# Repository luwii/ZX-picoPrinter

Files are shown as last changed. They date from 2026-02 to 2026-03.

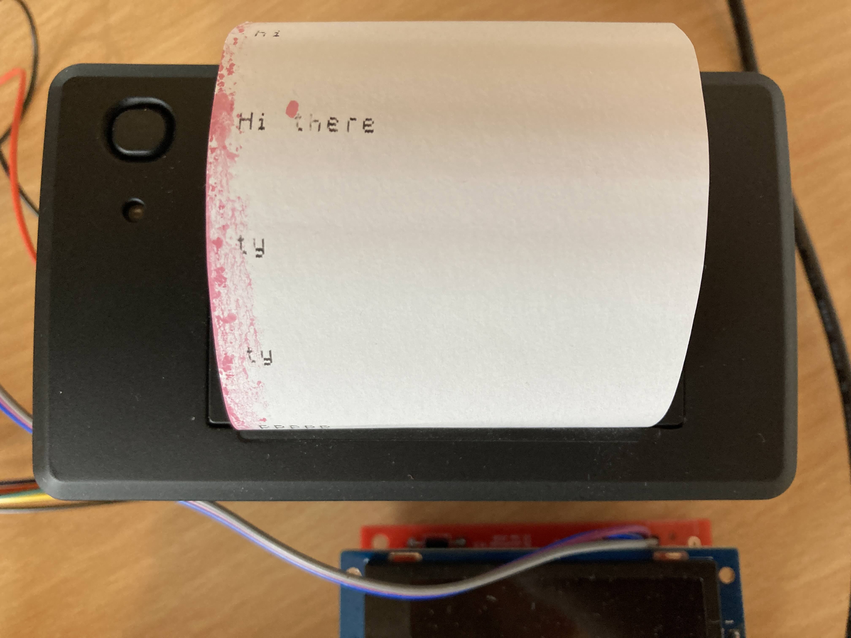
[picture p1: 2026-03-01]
Documentation/zx_printout.jpeg

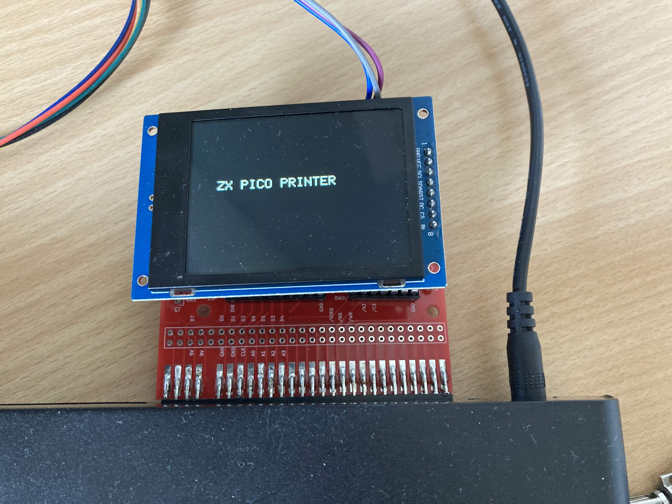
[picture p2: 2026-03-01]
Documentation/zx_screen.jpeg

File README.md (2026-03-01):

# ZX-picoPrinter

## Project Description
ZX-picoPrinter is a compact and efficient printer solution designed for use with the Raspberry Pi Pico. This project aims to provide an easy-to-use interface that is simple to construct.

## Features
- Compact design suitable for various projects
- Easy setup and integration with Raspberry Pi Pico
- Optional screen to preview the print

## Hardware Requirements
- Raspberry Pi Pico
- Compatible thermal printer
- Power supply for the printer
- Connecting cables (USB or serial)
- Custom circuit board 
- Logic chips

## Getting Started Guide
1. **Prerequisites**: Make sure you have installed the necessary software tools for Raspberry Pi Pico development. (VSC with official PI plugin was used)
2. **Clone the Repository**: ```git clone https://github.com/luwii/ZX-picoPrinter.git``` 
3. **Connect the Hardware**: Follow the wiring instructions provided in the documentation. The screen and printer work indepently, you only need one of them
4. **Upload the Code**: Use your preferred development environment to upload the provided codes to the Raspberry Pi Pico.
5. **Run the Application**: Start the application and test with LPRINT

## Documentation References
- [Printer Manual](https://github.com/luwii/ZX-picoPrinter/blob/main/Documentation/zxpicoprinter.pdf)
- [Raspberry Pi Pico Documentation](https://www.raspberrypi.com/documentation/microcontrollers/pico-series.html)

## License
This project is licensed under the MIT License. See the LICENSE file for more details.

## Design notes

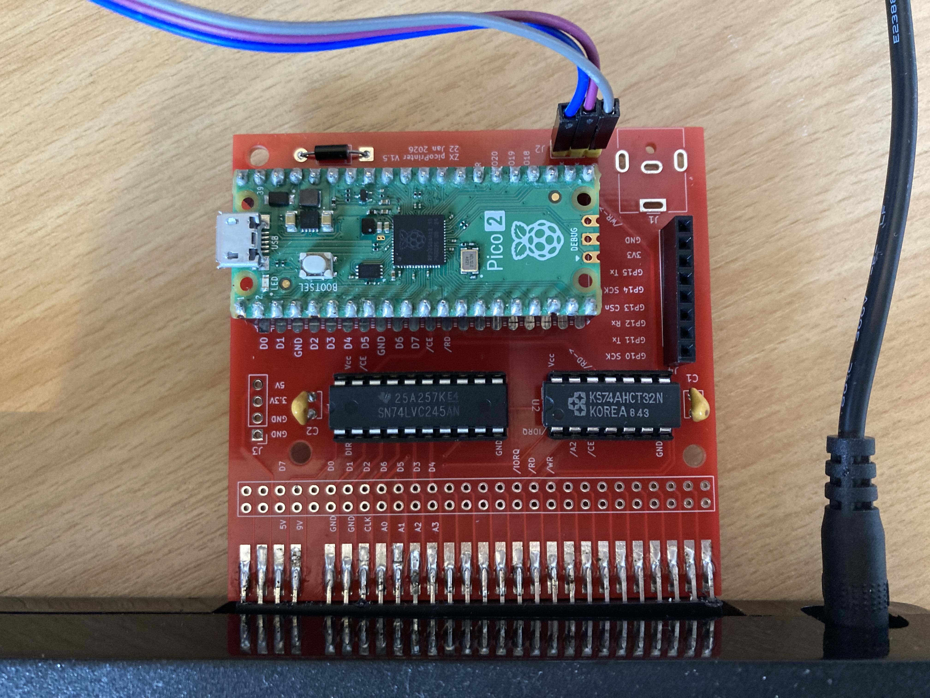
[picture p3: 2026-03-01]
Documentation/zx_board.jpeg

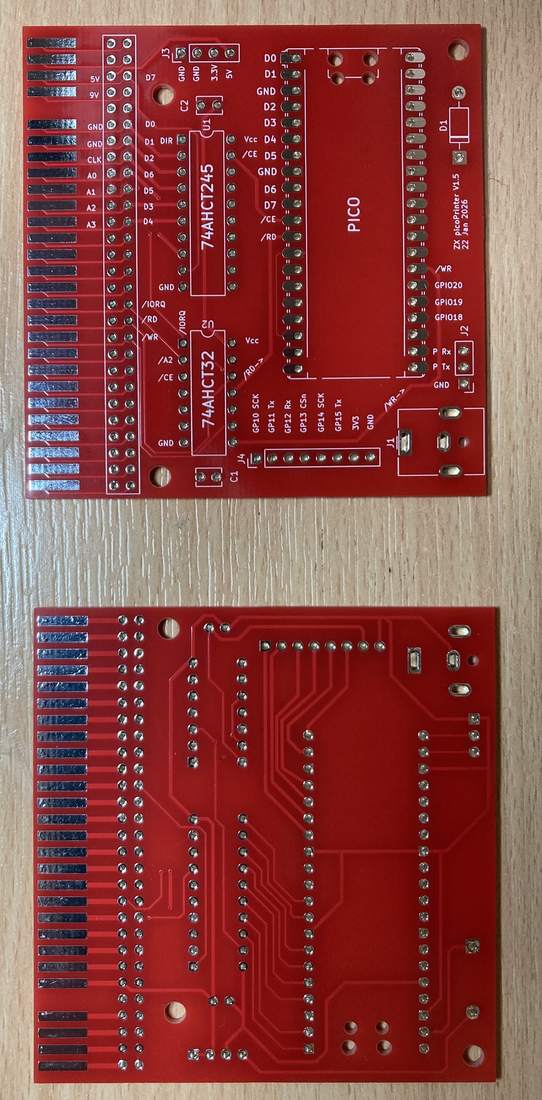
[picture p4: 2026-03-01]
Documentation/zx_pcb.jpeg

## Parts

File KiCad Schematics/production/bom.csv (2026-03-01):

Designator | Footprint | Quantity | Value | LCSC Part #
A1 | RaspberryPi_Pico_Common_Unspecified | 1 | RaspberryPi_Pico
C1, C2 | C_Disc_D3.8mm_W2.6mm_P2.50mm | 2 | C_Small
D1 | D_DO-41_SOD81_P10.16mm_Horizontal | 1 | 1N4004
J2 | PinHeader_1x03_P2.54mm_Vertical | 1 | Serial
J3 | PinHeader_1x04_P2.54mm_Vertical | 1 | Power
J4 | PinHeader_1x08_P2.54mm_Vertical | 1 | Conn_01x08_Pin
U1 | DIP-20_W7.62mm | 1 | 74AHCT245
U2 | CERDIP-14_W7.62mm_SideBrazed | 1 | 74AHCT32
Z1 | ZX_Bus_Edge_Connector | 1 | ZX48Bus
Z2 | ZX_Bus_Pin_Header | 1 | ZX48Bus

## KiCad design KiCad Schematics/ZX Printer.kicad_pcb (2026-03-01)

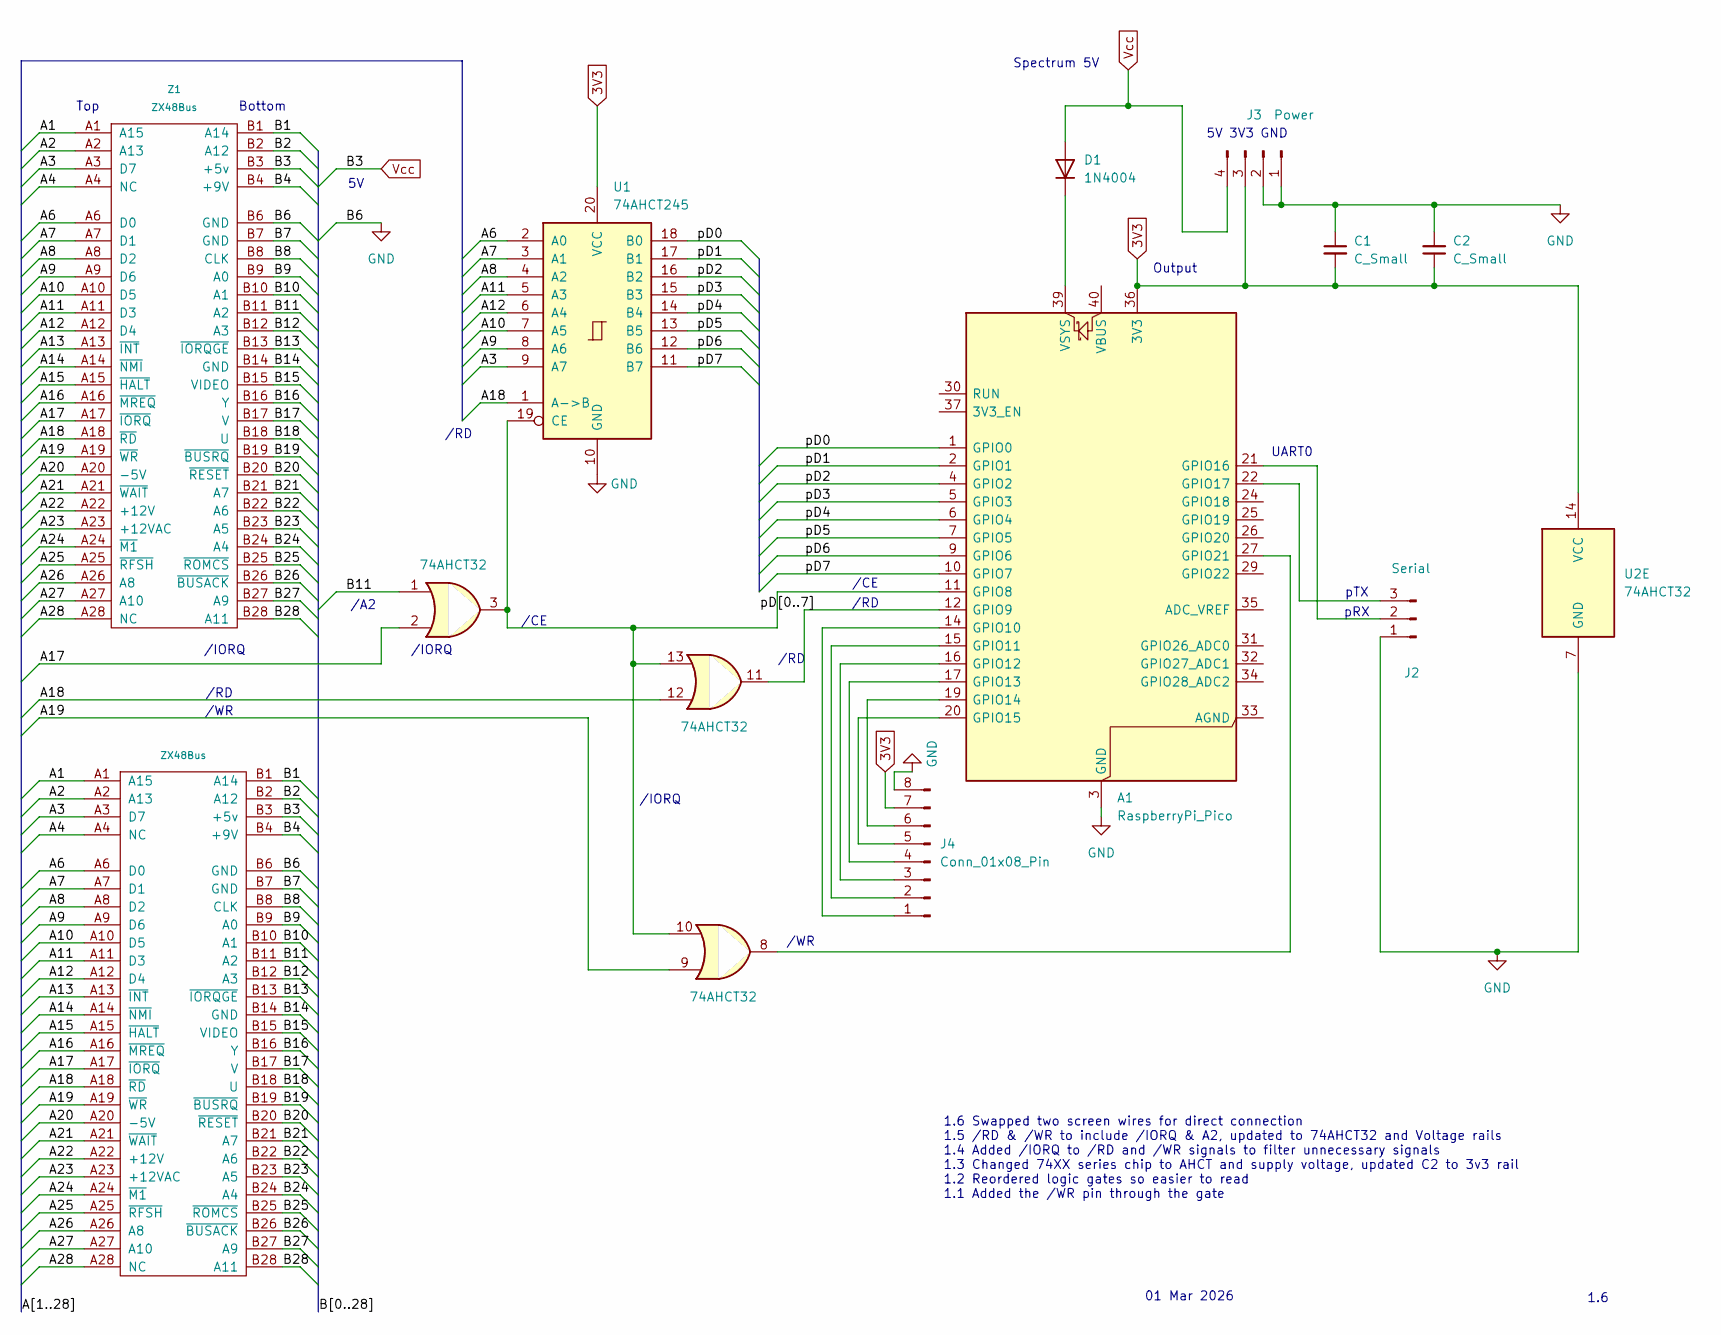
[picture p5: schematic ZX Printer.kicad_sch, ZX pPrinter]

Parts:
A1: RaspberryPi_Pico; RaspberryPi_Pico_Common_Unspecified
C1, C2: C_Small; C_Disc_D3.8mm_W2.6mm_P2.50mm
D1: 1N4004; D_DO-41_SOD81_P10.16mm_Horizontal
J2: Serial; PinHeader_1x03_P2.54mm_Vertical
J3: Power; PinHeader_1x04_P2.54mm_Vertical
J4: Conn_01x08_Pin; PinHeader_1x08_P2.54mm_Vertical
U1: 74AHCT245; DIP-20_W7.62mm
U2: 74AHCT32; CERDIP-14_W7.62mm_SideBrazed
Z1: ZX48Bus; ZX_Bus_Edge_Connector
Z2: ZX48Bus; ZX_Bus_Pin_Header

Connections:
3V3: A1.36 (3V3), C1.2, C2.1, J3.3, J4.7, U1.20 (VCC), U2.14 (VCC)
/A1: Z1.A1 (A15), Z2.A1 (A15)
/A2: Z1.A2 (A13), Z2.A2 (A13)
/A3: U1.9 (A7), Z1.A3 (D7), Z2.A3 (D7)
/A4: Z1.A4 (NC), Z2.A4 (NC)
/A6: U1.2 (A0), Z1.A6 (D0), Z2.A6 (D0)
/A7: U1.3 (A1), Z1.A7 (D1), Z2.A7 (D1)
/A8: U1.4 (A2), Z1.A8 (D2), Z2.A8 (D2)
/A9: U1.8 (A6), Z1.A9 (D6), Z2.A9 (D6)
/A10: U1.7 (A5), Z1.A10 (D5), Z2.A10 (D5)
/A11: U1.5 (A3), Z1.A11 (D3), Z2.A11 (D3)
/A12: U1.6 (A4), Z1.A12 (D4), Z2.A12 (D4)
/A13: Z1.A13 (~INT), Z2.A13 (~INT)
/A14: Z1.A14 (~NMI), Z2.A14 (~NMI)
/A15: Z1.A15 (~HALT), Z2.A15 (~HALT)
/A16: Z1.A16 (~MREQ), Z2.A16 (~MREQ)
/A17: U2.2, Z1.A17 (~IORQ), Z2.A17 (~IORQ)
/A18: U1.1 (A->B), U2.12, Z1.A18 (~RD), Z2.A18 (~RD)
/A19: U2.9, Z1.A19 (~WR), Z2.A19 (~WR)
/A20: Z1.A20 (-5V), Z2.A20 (-5V)
/A21: Z1.A21 (~WAIT), Z2.A21 (~WAIT)
/A22: Z1.A22 (+12V), Z2.A22 (+12V)
/A23: Z1.A23 (+12VAC), Z2.A23 (+12VAC)
/A24: Z1.A24 (~M1), Z2.A24 (~M1)
/A25: Z1.A25 (~RFSH), Z2.A25 (~RFSH)
/A26: Z1.A26 (A8), Z2.A26 (A8)
/A27: Z1.A27 (A10), Z2.A27 (A10)
/A28: Z1.A28 (NC), Z2.A28 (NC)
/B1: Z1.B1 (A14), Z2.B1 (A14)
/B2: Z1.B2 (A12), Z2.B2 (A12)
/B4: Z1.B4 (+9V), Z2.B4 (+9V)
/B7: Z1.B7 (GND), Z2.B7 (GND)
/B8: Z1.B8 (CLK), Z2.B8 (CLK)
/B9: Z1.B9 (A0), Z2.B9 (A0)
/B10: Z1.B10 (A1), Z2.B10 (A1)
/B11: U2.1, Z1.B11 (A2), Z2.B11 (A2)
/B12: Z1.B12 (A3), Z2.B12 (A3)
/B13: Z1.B13 (~IORQGE), Z2.B13 (~IORQGE)
/B14: Z1.B14 (GND), Z2.B14 (GND)
/B15: Z1.B15 (VIDEO), Z2.B15 (VIDEO)
/B16: Z1.B16 (Y), Z2.B16 (Y)
/B17: Z1.B17 (V), Z2.B17 (V)
/B18: Z1.B18 (U), Z2.B18 (U)
/B19: Z1.B19 (~BUSRQ), Z2.B19 (~BUSRQ)
/B20: Z1.B20 (~RESET), Z2.B20 (~RESET)
/B21: Z1.B21 (A7), Z2.B21 (A7)
/B22: Z1.B22 (A6), Z2.B22 (A6)
/B23: Z1.B23 (A5), Z2.B23 (A5)
/B24: Z1.B24 (A4), Z2.B24 (A4)
/B25: Z1.B25 (~ROMCS), Z2.B25 (~ROMCS)
/B26: Z1.B26 (~BUSACK), Z2.B26 (~BUSACK)
/B27: Z1.B27 (A9), Z2.B27 (A9)
/B28: Z1.B28 (A11), Z2.B28 (A11)
/pD0: A1.1 (GPIO0), U1.18 (B0)
/pD1: A1.2 (GPIO1), U1.17 (B1)
/pD2: A1.4 (GPIO2), U1.16 (B2)
/pD3: A1.5 (GPIO3), U1.15 (B3)
/pD4: A1.6 (GPIO4), U1.14 (B4)
/pD5: A1.7 (GPIO5), U1.13 (B5)
/pD6: A1.9 (GPIO6), U1.12 (B6)
/pD7: A1.10 (GPIO7), U1.11 (B7)
GND: A1.3 (GND), A1.8 (GND), A1.13 (GND), A1.18 (GND), A1.23 (GND), A1.28 (GND), A1.38 (GND), C1.1, C2.2, J2.1, J3.1, J3.2, J4.8, U1.10 (GND), U2.7 (GND), Z1.B6 (GND), Z2.B6 (GND)
unnamed: A1.11 (GPIO8), U1.19 (CE), U2.3, U2.10, U2.13
unnamed: A1.12 (GPIO9), U2.11
unnamed: A1.14 (GPIO10), J4.1
unnamed: A1.15 (GPIO11), J4.2
unnamed: A1.16 (GPIO12), J4.3
unnamed: A1.17 (GPIO13), J4.4
unnamed: A1.19 (GPIO14), J4.6
unnamed: A1.20 (GPIO15), J4.5
unnamed: A1.21 (GPIO16), J2.2
unnamed: A1.22 (GPIO17), J2.3
unnamed: A1.27 (GPIO21), U2.8
unnamed: A1.39 (VSYS), D1.1 (K)
Vcc: D1.2 (A), J3.4, Z1.B3 (+5v), Z2.B3 (+5v)

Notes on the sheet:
3V3
/IORQ
UART0
Bottom
/WR
/RD
1.6
/CE
Top
Spectrum 5V
GND
Output
/A2
pTX
01 Mar 2026
1.6 Swapped two screen wires for direct connection 1.5 /RD & /WR to include /IORQ & A2, updated to 74AHCT32 and Voltage rails 1.4 Added /IORQ to /RD and /WR signals to filter unnecessary signals 1.3 Changed 74XX series chip to AHCT and supply voltage, updated C2 to 3v3 rail 1.2 Reordered logic gate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
pRX

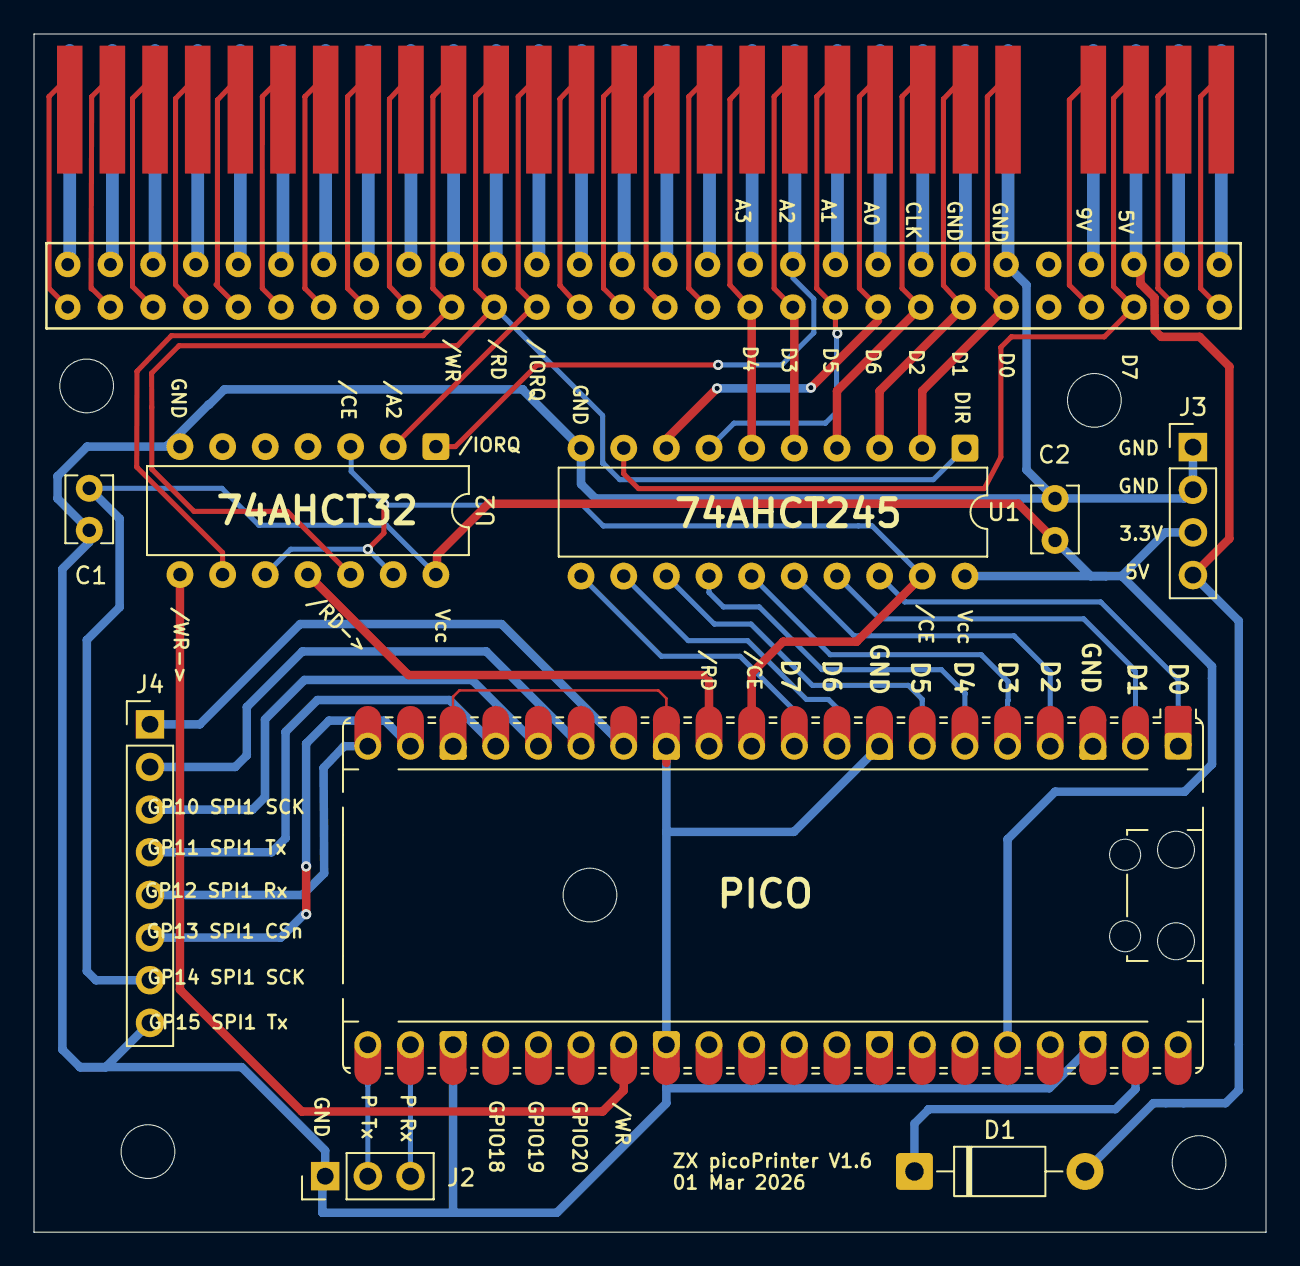
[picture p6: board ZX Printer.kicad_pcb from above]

Board: 2 copper layers, 73.4 x 71.4 mm, 11 parts (0 on the bottom side), 75 nets.

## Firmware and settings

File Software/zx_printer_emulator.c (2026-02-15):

#include <stdio.h>
#include <string.h>
#include <stdlib.h>
#include "pico/stdlib.h"
#include "hardware/pio.h"
#include "hardware/dma.h"
#include "hardware/spi.h"
#include "hardware/uart.h"
#include "zx_printer_emulator.pio.h"
#include "st7789.h"

// --- EM5820 Printer Definitions ---
#define PRINTER_UART uart0
#define PRINTER_BAUD 9600
#define PRINTER_TX_PIN 16
#define PRINTER_RX_PIN 17

// --- ZX Printer Emulator Definitions ---
#define DEBUG_VERBOSE 1
#define DISPLAY_MODE 0  // 0 = first 80 pixels, 1 = last 80 pixels for debug dump
#define ZX_DATA_BASE 0
#define ZX_CS_PIN 8
#define ZX_PRD_PIN 9
#define DEBUG_PIN 18
#define ZX_PWR_PIN 21

static int PRINTER_SCALE_H_PERCENT = 100;
static int PRINTER_SCALE_V_PERCENT = 100;

// --- ST7789 Display Pins ---
#define DISP_SCK 10
#define DISP_MOSI 11
#define DISP_RST 13
#define DISP_DC 12
#define DISP_CS 14
#define DISP_BL 15

// ESC/POS Constants
const uint8_t CMD_INIT[] = {0x1B, 0x40};

// Buffer size
#define BUFFER_SIZE 65536
static uint8_t buffer[BUFFER_SIZE];
static uint8_t cleaned[BUFFER_SIZE];  // Cleaned pixel-only buffer

// --- Clean buffer: parse and extract only pixel bytes, skipping controls ---
uint32_t clean_pixel_buffer(uint8_t* raw, uint32_t raw_size) {
    uint32_t cleaned_idx = 0;
    uint32_t skipped = 0;
    uint32_t i = 0;

    while (i < raw_size) {
        uint8_t b = raw[i];
        if (b == 0x04) {  // Skip stop (motor off)
            skipped++;
            i++;
            continue;
        }
        if (b == 0x00 || b == 0x02) {  // Speed byte: skip it, then copy next 256 pixels
            skipped++;
            i++;
            for (uint32_t p = 0; p < 256 && i < raw_size; p++) {
                // Copy pixel byte (may be 0x00/0x02/0x80/0x82)
                cleaned[cleaned_idx++] = raw[i];
                i++;
            }
            continue;
        }
        // Unexpected byte: skip (e.g., BREAK or error cases)
        skipped++;
        i++;
    }

    // Warn if incomplete last line
    if (cleaned_idx % 256 != 0 && DEBUG_VERBOSE && stdio_usb_connected()) {
        printf("Warning: Incomplete last line (%lu extra bytes)\n", (unsigned long)(cleaned_idx % 256));
    }

    if (DEBUG_VERBOSE && stdio_usb_connected()) {
        printf("Cleaned buffer: %lu bytes (skipped %lu control/unexpected bytes)\n", 
               (unsigned long)cleaned_idx, (unsigned long)skipped);
    }

    return cleaned_idx;
}

// --- Thermal print function (updated to use clean pixel stream) ---
void print_buffer_to_thermal(uint8_t *buf, uint32_t num_lines, bool unused_is_copy) {
    (void)unused_is_copy;  // No longer needed

    // Set line spacing to 0 for continuous image
    const uint8_t cmd_no_spacing[] = {0x1B, 0x33, 0x00};
    uart_write_blocking(PRINTER_UART, cmd_no_spacing, 3);

    const int src_w = 256;
    const int src_h = (int)num_lines;

    int dst_w = (src_w * PRINTER_SCALE_H_PERCENT + 50) / 100; if (dst_w < 1) dst_w = 1;
    int dst_h = (src_h * PRINTER_SCALE_V_PERCENT + 50) / 100; if (dst_h < 1) dst_h = 1;

    uint8_t *dst = calloc(dst_w * dst_h, 1);
    if (!dst) {
        dst_w = src_w; dst_h = src_h;
    }

    // Area-averaging downscale
    for (int dy = 0; dy < dst_h; dy++) {
        int sy0 = (dy * src_h) / dst_h;
        int sy1 = ((dy + 1) * src_h) / dst_h - 1;
        if (sy1 < sy0) sy1 = sy0;
        for (int dx = 0; dx < dst_w; dx++) {
            int sx0 = (dx * src_w) / dst_w;
            int sx1 = ((dx + 1) * src_w) / dst_w - 1;
            if (sx1 < sx0) sx1 = sx0;
            int total = (sx1 - sx0 + 1) * (sy1 - sy0 + 1);
            int ones = 0;
            for (int sy = sy0; sy <= sy1; sy++) {
                uint32_t pixel_start = sy * 256;  // Now always 256-byte lines
                for (int sx = sx0; sx <= sx1; sx++) {
                    uint32_t idx = pixel_start + sx;
                    if (idx < BUFFER_SIZE && (buf[idx] & 0x80)) ones++;
                }
            }
            if (dst) dst[dy * dst_w + dx] = (ones * 2 >= total) ? 1 : 0;
        }
    }

    // Send as ESC/POS graphics (8-dot mode)
    for (int row_base = 0; row_base < dst_h; row_base += 8) {
        int n = dst_w;
        uint8_t header[5] = {0x1B, 0x2A, 0x00, (uint8_t)(n & 0xFF), (uint8_t)((n >> 8) & 0xFF)};
        uart_write_blocking(PRINTER_UART, header, sizeof(header));

        for (int col = 0; col < dst_w; col++) {
            uint8_t out = 0;
            for (int bit = 0; bit < 8; bit++) {
                int dy = row_base + bit;
                if (dy >= dst_h) break;
                uint8_t pix = dst ? dst[dy * dst_w + col] : 0;
                if (pix) out |= (1u << (7 - bit));
            }
            uart_write_blocking(PRINTER_UART, &out, 1);
        }
        uint8_t lf = 0x0A;
        uart_write_blocking(PRINTER_UART, &lf, 1);
        sleep_ms(2);
    }

    if (dst) free(dst);
    const uint8_t cmd_reset_spacing[] = {0x1B, 0x32};
    uart_write_blocking(PRINTER_UART, cmd_reset_spacing, 2);
}

// Debug helper: print cleaned captured pixel data to USB stdio as ASCII art.
// Runs only when `DEBUG_VERBOSE` is enabled; respects `DISPLAY_MODE` and
// a configurable pixel count for the dump.
static void debug_print_cleaned_dump(uint8_t *cleaned_buf, uint32_t cleaned_size, uint32_t num_lines) {
#if DEBUG_VERBOSE
    const uint32_t DEBUG_DISPLAY_PIXELS = 80; // change this to show different widths
    uint32_t display_pixels = DEBUG_DISPLAY_PIXELS;
    uint32_t pixel_offset = (DISPLAY_MODE == 0) ? 0 : (256 - display_pixels);

    printf("\n=== DEBUG: Cleaned data dump ===\n");
    printf("Lines: %lu, Display pixels: %lu, Offset: %lu\n",
           (unsigned long)num_lines, (unsigned long)display_pixels, (unsigned long)pixel_offset);

    for (uint32_t line = 0; line < num_lines; line++) {
        printf("Line %3lu: ", (unsigned long)line);
        uint32_t pixel_start = line * 256;
        for (uint32_t pixel = 0; pixel < display_pixels; pixel++) {
            uint32_t idx = pixel_start + pixel_offset + pixel;
            if (idx < cleaned_size) {
                uint8_t data = cleaned_buf[idx];
                printf("%c", (data & 0x80) ? '#' : ' ');
            } else {
                printf(" ");
            }
        }
        printf("\n");
    }
    printf("=== End DEBUG dump ===\n\n");
#endif
}

int main() {
    stdio_init_all();

    // 1. Init thermal printer UART
    uart_init(PRINTER_UART, PRINTER_BAUD);
    uart_set_format(PRINTER_UART, 8, 1, UART_PARITY_NONE);
    gpio_set_function(PRINTER_TX_PIN, GPIO_FUNC_UART);
    gpio_set_function(PRINTER_RX_PIN, GPIO_FUNC_UART);
    sleep_ms(1000);
    uart_write_blocking(PRINTER_UART, CMD_INIT, sizeof(CMD_INIT));

    // Debug blinker if verbose
#if DEBUG_VERBOSE
    gpio_init(DEBUG_PIN);
    gpio_set_dir(DEBUG_PIN, GPIO_OUT);
    for (int i = 0; i < 5; i++) {
        gpio_put(DEBUG_PIN, 1);
        uart_puts(PRINTER_UART, "DEBUG_VERBOSE is on\n");
        sleep_ms(100);
        gpio_put(DEBUG_PIN, 0);
        sleep_ms(100);
    }
#endif

    // 2. Init ST7789 display
    st7789_config_t display_cfg = {
        .spi = spi1, .pin_sck = DISP_SCK, .pin_mosi = DISP_MOSI,
        .pin_rst = DISP_RST, .pin_dc = DISP_DC, .pin_cs = DISP_CS, .pin_bl = DISP_BL
    };
    st7789_init(&display_cfg);
    st7789_fill_screen(ST7789_BLACK);
    st7789_draw_string(40, 100, "ZX PICO PRINTER", ST7789_WHITE, ST7789_BLACK, 2);
    st7789_fill_rect(220, 0, 100, 240, ST7789_BLACK);

    if (stdio_usb_connected()) {
        printf("\n====================================\n");
        printf("ZX Printer Emulator & EM5820\n");
        printf("====================================\n");
    }

    // 3. ZX bus GPIO setup
    gpio_init(ZX_CS_PIN); gpio_init(ZX_PRD_PIN); gpio_init(ZX_PWR_PIN);
    gpio_set_dir(ZX_CS_PIN, GPIO_IN);
    gpio_set_dir(ZX_PRD_PIN, GPIO_IN);
    gpio_set_dir(ZX_PWR_PIN, GPIO_IN);
    gpio_pull_up(ZX_CS_PIN);
    gpio_pull_up(ZX_PRD_PIN);
    gpio_pull_up(ZX_PWR_PIN);

    // 4. PIO setup
    PIO pio = pio0;
    uint offset = pio_add_program(pio, &zx_printer_emulator_program);
    uint sm = pio_claim_unused_sm(pio, true);
    pio_sm_config c = zx_printer_emulator_program_get_default_config(offset);
    sm_config_set_in_pins(&c, ZX_DATA_BASE);
    sm_config_set_out_pins(&c, ZX_DATA_BASE, 8);
    sm_config_set_set_pins(&c, ZX_DATA_BASE, 8);
    sm_config_set_sideset_pins(&c, DEBUG_PIN);
    sm_config_set_in_shift(&c, false, true, 8);
    sm_config_set_jmp_pin(&c, ZX_PRD_PIN);
    pio_sm_init(pio, sm, offset, &c);
    for (int i = 0; i < 8; i++) pio_gpio_init(pio, ZX_DATA_BASE + i);
    pio_gpio_init(pio, DEBUG_PIN);
    pio_sm_set_consecutive_pindirs(pio, sm, DEBUG_PIN, 1, true);
    pio_sm_set_pins_with_mask(pio, sm, 0, (1u << DEBUG_PIN));
    pio_sm_put_blocking(pio, sm, 0x81);

    // 5. DMA setup
    int dma_chan = dma_claim_unused_channel(true);
    dma_channel_config dma_config = dma_channel_get_default_config(dma_chan);
    channel_config_set_transfer_data_size(&dma_config, DMA_SIZE_8);
    channel_config_set_read_increment(&dma_config, false);
    channel_config_set_write_increment(&dma_config, true);
    channel_config_set_dreq(&dma_config, pio_get_dreq(pio, sm, false));
    dma_channel_configure(dma_chan, &dma_config, buffer, &pio->rxf[sm], BUFFER_SIZE, false);

    pio_sm_set_enabled(pio, sm, true);
    dma_channel_start(dma_chan);

    uint32_t buffer_index = 0, idle_count = 0;
    const uint32_t IDLE_THRESHOLD = 500000;

    while (true) {
        uint32_t bytes_transferred = BUFFER_SIZE - dma_channel_hw_addr(dma_chan)->transfer_count;
        if (bytes_transferred > buffer_index) {
            buffer_index = bytes_transferred;
            idle_count = 0;
        } else {
            idle_count++;
            if (idle_count >= IDLE_THRESHOLD && buffer_index > 0) {
                // Clean the buffer first
                uint32_t cleaned_size = clean_pixel_buffer(buffer, buffer_index);
                uint32_t num_lines = cleaned_size / 256;

                if (DEBUG_VERBOSE && stdio_usb_connected()) {
                    printf("Captured: %lu bytes → %lu clean pixel bytes → %lu lines\n",
                           (unsigned long)buffer_index, (unsigned long)cleaned_size, (unsigned long)num_lines);
                }

                // Optional: print cleaned pixel buffer (moved to helper for readability)
#if DEBUG_VERBOSE
                debug_print_cleaned_dump(cleaned, cleaned_size, num_lines);
#endif

                // Render to ST7789 (using cleaned buffer)
                st7789_fill_screen(ST7789_WHITE);
                uint32_t max_display_lines = (num_lines > 240) ? 240 : num_lines;
                for (uint32_t line = 0; line < max_display_lines; line++) {
                    uint32_t pixel_start = line * 256;
                    for (uint32_t pixel = 0; pixel < 256; pixel++) {
                        uint32_t idx = pixel_start + pixel;
                        if (idx < cleaned_size && (cleaned[idx] & 0x80)) {
                            st7789_draw_pixel(32 + pixel, 32 + line, ST7789_BLACK);
                        }
                    }
                }

                // Send to thermal printer
                print_buffer_to_thermal(cleaned, num_lines, false);  // is_copy ignored
                uart_puts(PRINTER_UART, "\n\n\n");

                // Reset DMA for next capture
                dma_channel_abort(dma_chan);
                dma_channel_set_write_addr(dma_chan, buffer, false);
                dma_channel_set_trans_count(dma_chan, BUFFER_SIZE, false);
                dma_channel_start(dma_chan);
                buffer_index = 0;
                idle_count = 0;
            }
            sleep_us(1);
        }
    }
}

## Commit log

2026-02-15 Delete ZX Printer.kicad_pcb
    Moved to Hardware folder
    [ZX Printer.kicad_pcb]
2026-02-15 Delete ZX Printer.kicad_pro
    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
2026-02-15 Delete ZX Printer.kicad_sch
    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
    [ZX Printer.kicad_sch]
2026-03-01 Fixed mounting holes
    [ZX Printer.kicad_pcb]
2026-03-01 Add source link for zxbus connector
    Added link to the original repository for the connector.
2026-03-01 Update README.md with original repo link
    Added a reference to the original repository for the connector.
2026-03-01 Create .gitignore file with content for KiCad, C/Embedded development, IDE files, and OS files
2026-05-18 Add files via upload
    Compiled Pico2 printer
2026-10-19 Update README with user attachment links
    Added links to user attachments in the README.
